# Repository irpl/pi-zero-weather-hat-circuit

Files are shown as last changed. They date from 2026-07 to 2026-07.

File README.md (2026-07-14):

# Raspberry Pi Zero Weather Station HAT — Circuit

Design and manufacturing files for a custom Raspberry Pi Zero HAT that drives a weather station kit. Fabricated November 2020.

The board reads temperature and humidity from a **BME280**, and interfaces the kit's outdoor sensors — a wind vane, an anemometer, and a tipping-bucket rain gauge — through two RJ11/RJ12 jacks. Because the Pi has no analogue inputs, an **MCP3008** ADC on the Pi's SPI bus reads the wind vane's resistive output.

The board outline, mounting holes, and GPIO header come from [mikelawrence/RPi_Zero_pHat_Template](https://github.com/mikelawrence/RPi_Zero_pHat_Template); everything else is my own design.

**Firmware:** [pi-weather](https://github.com/irpl/pi-weather) — the Python that runs on the Pi.

| Gerber render — top | Gerber render — bottom |
|---|---|
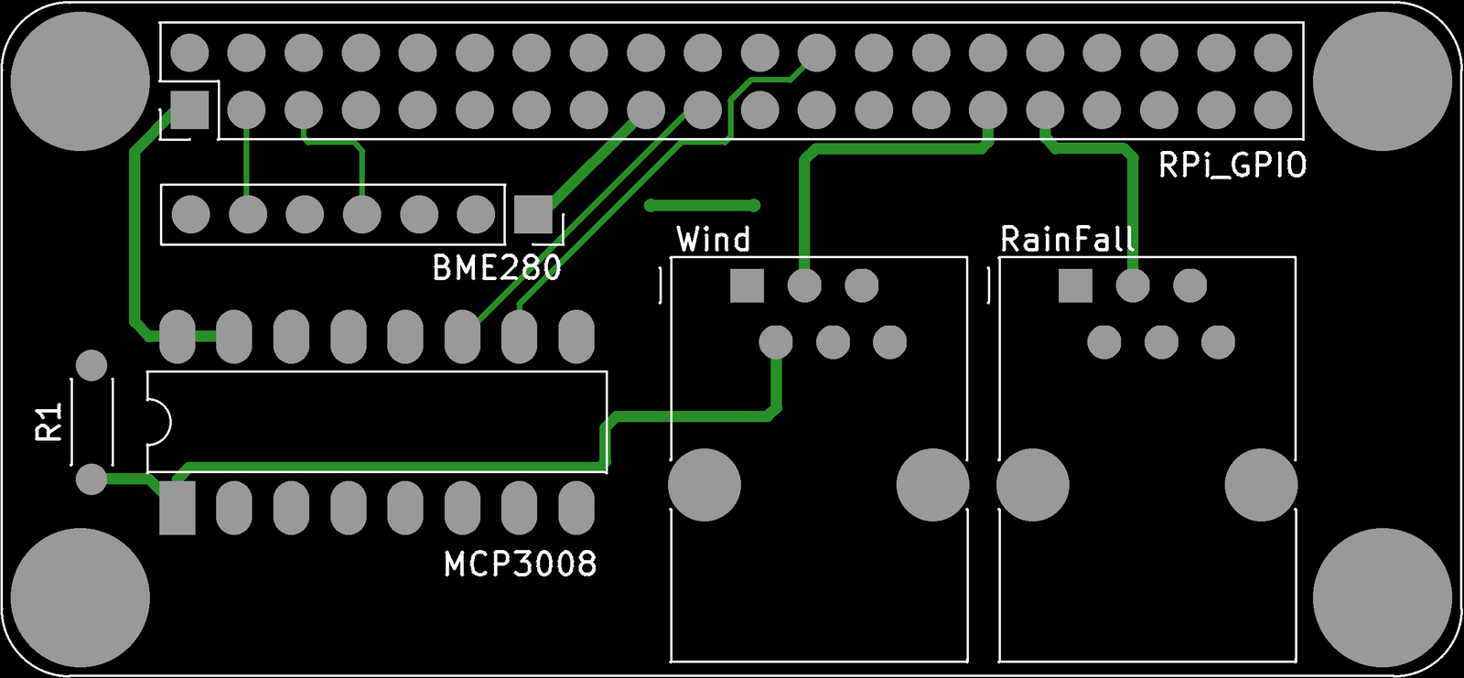
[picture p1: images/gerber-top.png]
Top
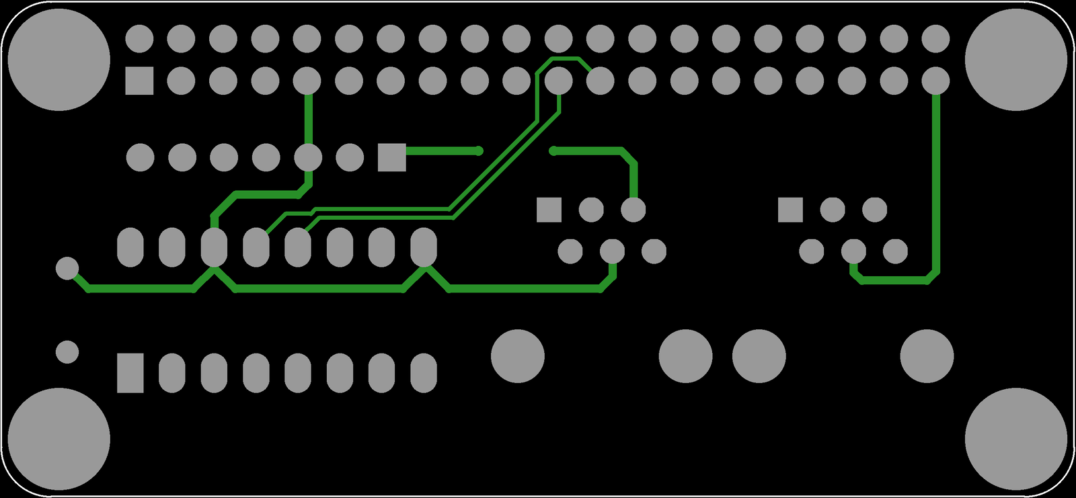
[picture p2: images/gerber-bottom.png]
Bottom
|  |  |

## Manufacturing files

[`gerbers/`](gerbers/) holds the exact set sent to the fab: Gerbers for both copper layers, soldermask, silkscreen, board outline, plus the Excellon drill file. The board is reproducible from these as-is.

- Two-layer, 65 × 30 mm (Raspberry Pi HAT form factor)
- 87 drilled holes; 7 drill sizes from 0.40 mm to 3.25 mm
- Generated by KiCad 5.1.6

## Reconstructed schematic and layout

**The original KiCad project files were lost.** Only the Gerbers survived, so the schematic and board in [`reconstructed/`](reconstructed/) were rebuilt from them — see [`reconstructed/`](reconstructed/) for the scripts that did it.

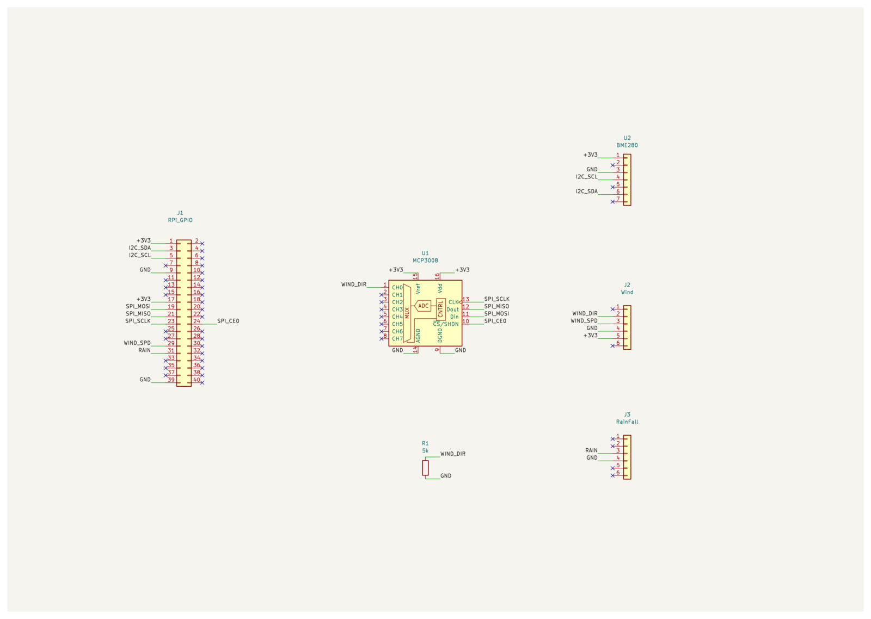
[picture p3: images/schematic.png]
Schematic


*Full resolution: [`reconstructed/schematic.pdf`](reconstructed/schematic.pdf). The recovered layout, plotted from the reconstructed `.kicad_pcb`:*

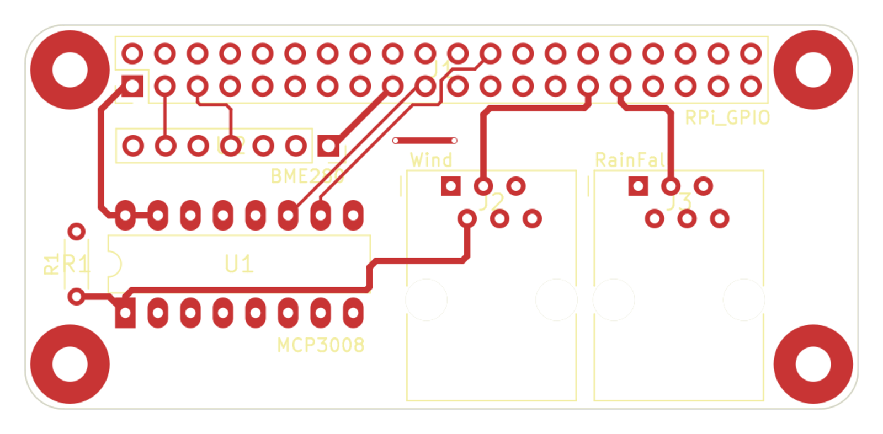
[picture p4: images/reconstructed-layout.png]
Reconstructed layout


The netlist is not a guess. Gerbers contain no connectivity, but the copper does: running a union-find over the pads and track segments (a plated hole ties the two layers together) recovers the netlist that was actually manufactured. That result is independently corroborated by the firmware — `wind_spd.py` uses `Button(5)` and the copper routes the Wind jack to GPIO5; `rain_fall.py` uses `Button(6)` and the copper routes RainFall to GPIO6; `wind_dir.py` reads `MCP3008(channel=0)` and the copper routes the vane to CH0.

### Circuit

- **MCP3008** on the Pi's hardware SPI — `SCLK`/`MISO`/`MOSI`/`CE0` on GPIO 11/9/10/8. `VDD` and `VREF` on 3V3.
- **Wind vane** — 3V3 feeds the vane through the Wind jack; the wiper returns to `CH0`, with **R1 (5 kΩ)** to ground forming the divider the ADC reads.
- **Anemometer** — reed switch to **GPIO5**.
- **Rain gauge** — reed switch to **GPIO6**.
- **BME280** — I²C on `GPIO2 (SDA)` / `GPIO3 (SCL)`, address `0x77`.

### Jack pinout

Both jacks use the standard staggered modular footprint: pin numbers advance across the connector, with odd pins in one row and even pins in the other.

| Jack | Pin 2 | Pin 3 | Pin 4 | Pin 5 |
|---|---|---|---|---|
| **Wind** (6P4C) | vane wiper → `CH0` | anemometer → GPIO5 | GND | +3V3 |
| **RainFall** (6P2C) | — | rain gauge → GPIO6 | GND | — |

The reed switches in the anemometer and rain gauge simply short their signal pin to GND; `gpiozero`'s `Button()` enables the Pi's internal pull-ups, so no pull-up resistors are fitted on the board.

**R1 = 5 kΩ.** Component values are not in Gerber data, but this one is pinned down two ways: the colour bands on the fitted resistor read green-black-red, and the empirical voltage table in [`wind_dir.py`](https://github.com/irpl/pi-weather/blob/main/src/wind_dir.py) matches a 5 kΩ divider against the standard vane resistances at every point — a 1 kΩ vane arm gives 3.3 × 5/6 = 2.75 V, and 2.75 is exactly what the table records for 90°.

### Fidelity of the reconstructed board

The `.kicad_pcb` is not a bare tracing: pads are grouped into components with reference designators and pin numbers, and the recovered netlist is applied to pads, tracks and vias. It opens with a working ratsnest and passes connectivity DRC. Contents: 6 components (77 pads), 8 unplated mounting holes, 2 vias, 100 tracks, 11 nets — 87 drilled holes in total, matching the drill file exactly.

Copper geometry was checked against the source Gerbers by re-plotting from the reconstruction and comparing: **0.000 mm difference in total track length on both layers**, pad positions within 1.6 µm (coordinate rounding in the 2020 files), and identical apertures and drill tools.

Two deliberate departures from the artwork, both improvements rather than losses:

- **The board outline is not drawn onto the copper layers.** KiCad 5 plotted Edge.Cuts onto F.Cu and B.Cu as well; that stroke is a plot artifact, not copper, so it is kept on Edge.Cuts only. Copying it into copper would put a trace exactly on the cut line.
- **Mounting-hole mask openings are taken from the mask Gerbers**, preserving the 6.2 mm soldermask keep-out rings around the RJ-jack mounting holes.

DRC reports 4 copper-to-edge-clearance and 1 soldermask-bridge violation. All five are faithful to the original artwork, not artefacts of the conversion: the 2020 design runs copper right up to the board edge and uses generous mask expansion on the 0.1″ headers. Two "unconnected" items are also expected — the +3V3 and GND rails each exist as two separate copper islands on the HAT (Pi pins 1/17 and 9/39) and are only bonded once the board is seated on the Pi.

One quirk faithfully preserved: a 0.66 mm dangling stub on GPIO25 (J1 pin 22), left over in the original copper and connected to nothing.

### What could not be recovered

Gerbers carry geometry, not design intent. These are stated rather than invented:

- **Component values**, other than R1 (5 kΩ, established above). Gerber data has no values, so no BOM can be generated from these files.
- **Library footprints.** Pads carry recovered geometry — correct size, shape, position and drill — but they are not linked to library footprints, so there is no 3D model or pick-and-place data.
- **Silkscreen text** is line art in the Gerbers, so in the reconstructed board it is strokes rather than editable text.

It is a re-spinnable, netlisted board — but it is a reconstruction, not the original project.

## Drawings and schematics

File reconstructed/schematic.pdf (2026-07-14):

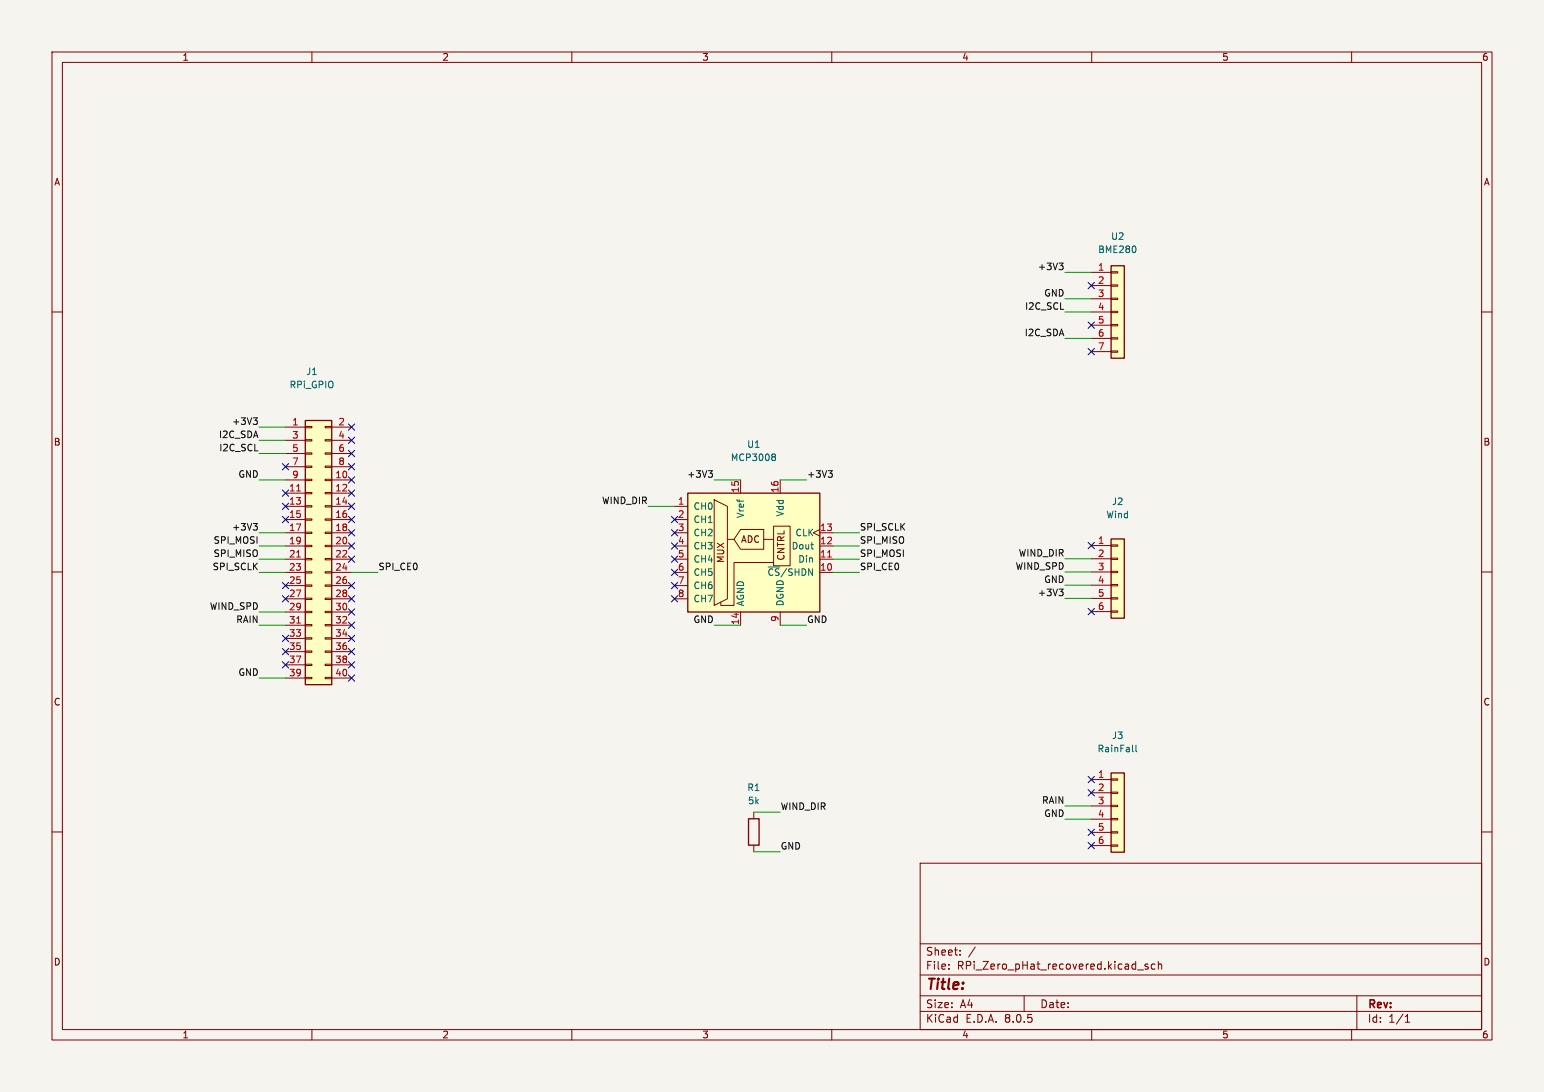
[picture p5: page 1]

Id: 1/1 Title: File: RPi_Zero_pHat_recovered.kicad_sch Sheet: /

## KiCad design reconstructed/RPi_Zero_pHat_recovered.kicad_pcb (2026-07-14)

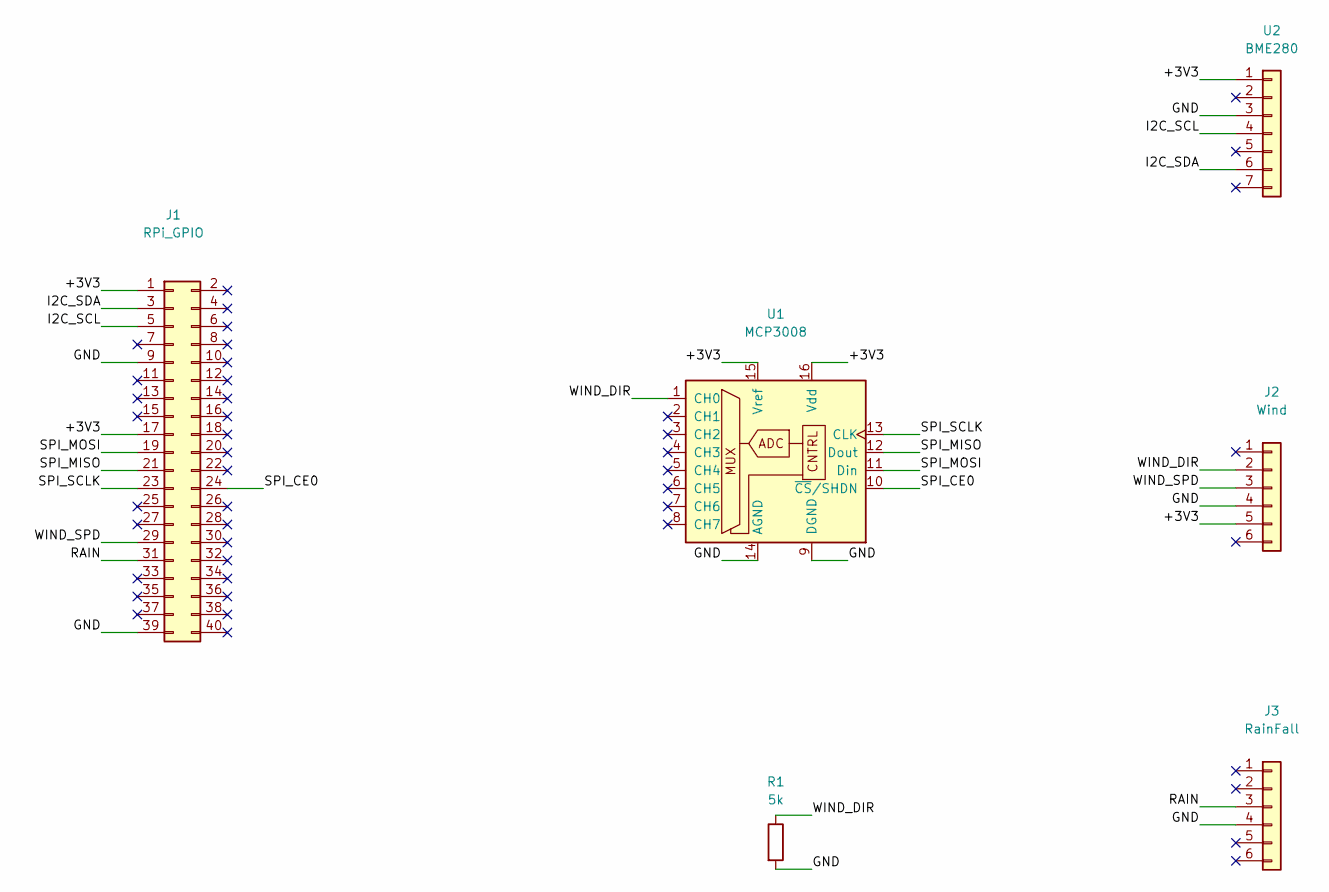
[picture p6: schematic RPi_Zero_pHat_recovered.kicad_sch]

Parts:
J1: RPi_GPIO
J2: Wind
J3: RainFall
R1: 5k
U1: MCP3008
U2: BME280

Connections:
+3V3: J1.1, J1.17, J2.5, U1.15 (Vref), U1.16 (Vdd), U2.1
GND: J1.9, J1.39, J2.4, J3.4, R1.2, U1.9 (DGND), U1.14 (AGND), U2.3
I2C_SCL: J1.5, U2.4
I2C_SDA: J1.3, U2.6
RAIN: J1.31, J3.3
SPI_CE0: J1.24, U1.10 (~CS/SHDN)
SPI_MISO: J1.21, U1.12 (Dout)
SPI_MOSI: J1.19, U1.11 (Din)
SPI_SCLK: J1.23, U1.13 (CLK)
WIND_DIR: J2.2, R1.1, U1.1 (CH0)
WIND_SPD: J1.29, J2.3

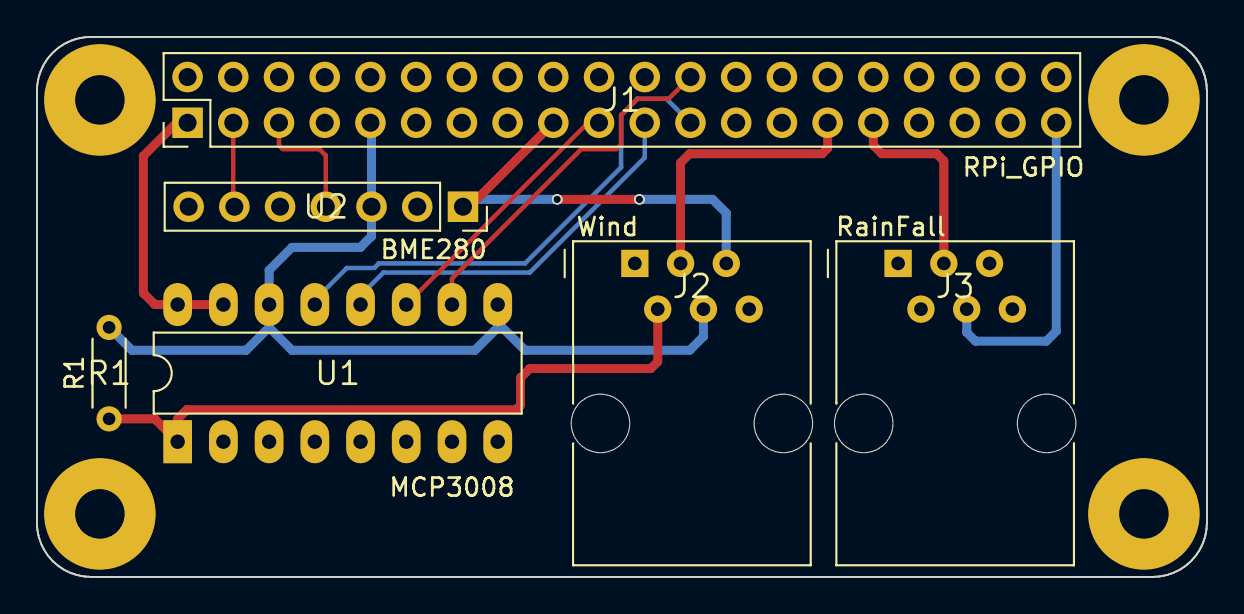
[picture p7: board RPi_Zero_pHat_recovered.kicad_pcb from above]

Board: 2 copper layers, 65.0 x 30.0 mm, 14 parts (0 on the bottom side), 11 nets.

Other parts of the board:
H1, H2, H3, H4, H5, H6, H7, H8: (no value)

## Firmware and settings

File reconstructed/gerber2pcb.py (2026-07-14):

"""Rebuild a netlisted .kicad_pcb from the 2020 JLCPCB Gerber + Excellon set.

Gerbers store artwork, not a design. This script recovers both:

  * geometry  - tracks, pads, vias, board outline and silkscreen, straight from the
                Gerber apertures and the Excellon drill table;
  * electrics - pads are grouped into components (from their pitch and rect pin-1
                markers), and the netlist is recovered by union-find over the copper
                (a plated hole ties F.Cu to B.Cu), then applied to pads, tracks and vias.

The result opens in KiCad with a ratsnest and passes connectivity DRC, unlike a
plain artwork tracing. What is NOT recoverable from Gerbers: component values
(R1 = 5k is known independently) and real footprints - pads carry recovered
geometry, not library footprints.

Run with KiCad's bundled Python, which provides `pcbnew`:
    "C:/Program Files/KiCad/8.0/bin/python.exe" gerber2pcb.py
"""
import re, math, collections
from pathlib import Path
import pcbnew

HERE = Path(__file__).resolve().parent
SRC  = HERE.parent / "gerbers"
OUT  = HERE / "RPi_Zero_pHat_recovered.kicad_pcb"
BASE = "RPi_Zero_pHat_Template"

def nm(mm):  return int(round(mm * 1e6))
def V(x, y): return pcbnew.VECTOR2I(nm(x), nm(-y))   # Gerber Y is up, KiCad Y is down

OUTLINE_W = 0.1    # KiCad 5 plots Edge.Cuts onto the copper layers too; that stroke
                   # is a plot artifact, not copper, and is excluded from the tracks.
VIA_DRILL = 0.45   # 0.40 mm hole + small round pad on both layers = via, not a part

# ---------------------------------------------------------------- gerber / drill
class Gerber:
    """Minimal RS-274X reader: apertures, D01 draws, D02 moves, D03 flashes, G02/G03 arcs."""
    def __init__(self, path):
        self.apertures, self.draws, self.arcs, self.flashes = {}, [], [], []
        self._parse(open(path, errors="ignore").read())

    def _parse(self, text):
        dec = int(re.search(r"%FSLAX(\d)(\d)Y\d\d\*%", text).group(2))
        for am in re.finditer(r"%ADD(\d+)([CROP]),([^*]+)\*%", text):
            self.apertures[int(am.group(1))] = (am.group(2),
                                                [float(v) for v in am.group(3).split("X")])
        scale = 10 ** dec
        x = y = 0.0
        ap = None
        interp = "G01"
        for line in text.splitlines():
            line = line.strip()
            if line.startswith("%") or line.startswith("G04"):
                continue
            dm = re.fullmatch(r"D(\d+)\*", line)
            if dm and int(dm.group(1)) >= 10:
                ap = int(dm.group(1)); continue
            for g in ("G01", "G02", "G03"):
                if line.startswith(g): interp = g
            cm = re.search(r"(?:X(-?\d+))?(?:Y(-?\d+))?(?:I(-?\d+))?(?:J(-?\d+))?D0?([123])\*", line)
            if not cm:
                continue
            nx = int(cm.group(1)) / scale if cm.group(1) else x
            ny = int(cm.group(2)) / scale if cm.group(2) else y
            i  = int(cm.group(3)) / scale if cm.group(3) else 0.0
            j  = int(cm.group(4)) / scale if cm.group(4) else 0.0
            op = cm.group(5)
            if op == "1":
                if interp == "G01": self.draws.append((x, y, nx, ny, ap))
                else:               self.arcs.append((x, y, nx, ny, x + i, y + j, interp == "G03", ap))
            elif op == "3":
                self.flashes.append((nx, ny, ap))
            x, y = nx, ny

def read_drill(path):
    tools, holes, unit_in, cur = {}, [], False, None
    for line in open(path, errors="ignore"):
        line = line.strip()
        if line == "INCH":   unit_in = True
        if line == "METRIC": unit_in = False
        tm = re.fullmatch(r"T(\d+)C([\d.]+)", line)
        if tm:
            d = float(tm.group(2))
            tools[int(tm.group(1))] = d * 25.4 if unit_in else d
            continue
        sm = re.fullmatch(r"T(\d+)", line)
        if sm:
            cur = int(sm.group(1)); continue
        cm = re.fullmatch(r"X(-?[\d.]+)Y(-?[\d.]+)", line)
        if cm and cur in tools:
            x, y = float(cm.group(1)), float(cm.group(2))
            if unit_in: x, y = x * 25.4, y * 25.4
            holes.append((x, y, tools[cur]))
    return holes

layers = {L: Gerber(SRC / f"{BASE}-{L}.gbr")
          for L in ("F_Cu", "B_Cu", "F_Mask", "B_Mask", "F_SilkS", "B_SilkS", "Edge_Cuts")}
holes = read_drill(SRC / f"{BASE}.drl")

# ---------------------------------------------------------------- pads & pin naming
# A plated hole spans both layers, so pads are keyed by position.
pads = {}
for L in ("F_Cu", "B_Cu"):
    g = layers[L]
    for (x, y, ap) in g.flashes:
        shape, dims = g.apertures[ap]
        k = (round(x, 2), round(y, 2))
        e = pads.setdefault(k, {"pos": (x, y), "shape": shape, "dims": dims})
        if shape == "R":                      # rectangular pad = pin 1
            e["shape"], e["dims"] = shape, dims

P = 2.54
def near(a, b, t=0.15): return abs(a - b) < t

RPI = {1:"3V3",2:"5V",3:"GPIO2_SDA",4:"5V",5:"GPIO3_SCL",6:"GND",7:"GPIO4",8:"GPIO14_TXD",
 9:"GND",10:"GPIO15_RXD",11:"GPIO17",12:"GPIO18",13:"GPIO27",14:"GND",15:"GPIO22",16:"GPIO23",
 17:"3V3",18:"GPIO24",19:"GPIO10_MOSI",20:"GND",21:"GPIO9_MISO",22:"GPIO25",23:"GPIO11_SCLK",
 24:"GPIO8_CE0",25:"GND",26:"GPIO7_CE1",27:"ID_SD",28:"ID_SC",29:"GPIO5",30:"GND",31:"GPIO6",
 32:"GPIO12",33:"GPIO13",34:"GND",35:"GPIO19",36:"GPIO16",37:"GPIO26",38:"GPIO20",39:"GND",40:"GPIO21"}

def classify(k):
    """pad key -> (refdes, pin number) using pitch and the rect pin-1 markers."""
    x, y = k
    if near(y, -29.27): return "J1", 2 * round((x - 20.87) / P) + 1
    if near(y, -26.73): return "J1", 2 * round((x - 20.87) / P) + 2
    if near(y, -46.99): return "U1", round((x - 20.32) / P) + 1          # MCP3008 pins 1-8
    if near(y, -39.37): return "U1", 9 + round((38.10 - x) / P)          # MCP3008 pins 9-16
    if near(y, -33.93): return "U2", round((36.17 - x) / P) + 1          # BME280, pin 1 at right
    # RJ11/RJ12 jacks: pads are staggered, not row-major. Pin number advances with x
    # (1.27 mm) while alternating rows - odd pins in pin-1's row, even pins in the other.
    # Contacts inside a modular jack sit side by side; their tails cannot cross.
    for ref, x0 in (("J2", 45.72), ("J3", 60.35)):
        if x0 - 0.2 <= x <= x0 + 6.6 and (near(y, -37.08) or near(y, -39.62)):
            return ref, round((x - x0) / 1.27) + 1
    if near(x, 16.51): return "R1", 1 if near(y, -45.72) else 2
    return None, None

# ---------------------------------------------------------------- recover the netlist
# union-find over pads and copper segments; a plated hole bridges the layers
parent = {}
def find(a):
    parent.setdefault(a, a)
    while parent[a] != a:
        parent[a] = parent[parent[a]]; a = parent[a]
    return a
def union(a, b):
    ra, rb = find(a), find(b)
    if ra != rb: parent[ra] = rb
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

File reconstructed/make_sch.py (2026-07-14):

"""Generate a KiCad schematic whose connectivity is exactly the netlist extracted
from the fabricated board's copper (see extract_nets.py / netlist.py).

Nets are attached with local labels at each pin. Pins the board leaves unconnected
get a no-connect flag, so the schematic states plainly what is and isn't wired.
"""
import re, uuid, os

from pathlib import Path

# Run with plain CPython:  python make_sch.py
# Override the symbol library location with KICAD_SYMBOL_DIR if KiCad lives elsewhere.
HERE = Path(__file__).resolve().parent
LIB  = os.environ.get("KICAD_SYMBOL_DIR", r"C:\Program Files\KiCad\8.0\share\kicad\symbols")
OUT  = HERE / "RPi_Zero_pHat_recovered.kicad_sch"

def U(): return str(uuid.uuid4())

# ---------------------------------------------------------------- symbol loading
def load_symbol(libname, symname):
    """Pull one top-level (symbol "NAME" ...) block out of a .kicad_sym file.

    Symbols may be defined as (extends "PARENT"), which inherits the parent's pins
    and graphics; in that case return the parent's body under the child's name.
    """
    txt = open(os.path.join(LIB, libname + ".kicad_sym"), encoding="utf-8").read()
    start = txt.index(f'(symbol "{symname}"')
    depth, i = 0, start
    while True:
        if txt[i] == "(": depth += 1
        elif txt[i] == ")":
            depth -= 1
            if depth == 0: break
        i += 1
    block = txt[start:i + 1]
    ext = re.search(r'\(extends\s+"([^"]+)"\)', block)
    if ext:
        parent = load_symbol(libname, ext.group(1))
        # keep the parent's body (pins/graphics), present it under the child's name
        pname = ext.group(1)
        block = parent.replace(f'(symbol "{pname}"', f'(symbol "{symname}"', 1)
        block = block.replace(f'(symbol "{pname}_', f'(symbol "{symname}_')   # unit sub-symbols
    return block

def symbol_pins(block):
    """[(number, name, x, y)] - pin connection points in symbol coords."""
    pins = []
    for m in re.finditer(
        r"\(pin\s+\w+\s+\w+\s*\(at\s+(-?[\d.]+)\s+(-?[\d.]+)\s+(-?[\d.]+)\)"
        r".*?\(name\s+\"([^\"]*)\".*?\(number\s+\"([^\"]*)\"",
        block, re.S):
        x, y, ang, nm, num = m.groups()
        pins.append((num, nm, float(x), float(y), float(ang)))
    return pins

PARTS = {                       # ref -> (lib, symbol, value, x, y, ref_dy)
    "J1": ("Connector_Generic", "Conn_02x20_Odd_Even", "RPi_GPIO",  60,  105, 31.0),
    "U1": ("Analog_ADC",        "MCP3008",             "MCP3008",  145,  105, 17.0),
    "U2": ("Connector_Generic", "Conn_01x07",          "BME280",   215,   60, 12.0),
    "J2": ("Connector_Generic", "Conn_01x06",          "Wind",     215,  110, 11.0),
    "J3": ("Connector_Generic", "Conn_01x06",          "RainFall", 215,  155, 11.0),
    "R1": ("Device",            "R",                   "5k",       145,  160,  6.0),
}

# net -> [(ref, pin), ...]   (taken verbatim from the copper extraction)
# RJ jack pads are staggered: pin number advances with x while alternating rows,
# so Wind lands on pins 2-5 (a 6P4C plug) and RainFall on the centre pair 3-4 (6P2C).
NETS = {
    "GND":      [("J1","9"),("J1","39"),("J2","4"),("J3","4"),("R1","2"),
                 ("U1","9"),("U1","14"),("U2","3")],
    "+3V3":     [("J1","1"),("J1","17"),("J2","5"),
                 ("U1","15"),("U1","16"),("U2","1")],
    "SPI_SCLK": [("J1","23"),("U1","13")],
    "SPI_MISO": [("J1","21"),("U1","12")],
    "SPI_MOSI": [("J1","19"),("U1","11")],
    "SPI_CE0":  [("J1","24"),("U1","10")],
    "I2C_SDA":  [("J1","3"),("U2","6")],
    "I2C_SCL":  [("J1","5"),("U2","4")],
    "WIND_SPD": [("J1","29"),("J2","3")],
    "RAIN":     [("J1","31"),("J3","3")],
    "WIND_DIR": [("J2","2"),("R1","1"),("U1","1")],
}

# ---------------------------------------------------------------- build
lib_blocks, pin_map = {}, {}
for ref, (lib, sym, val, sx, sy, rdy) in PARTS.items():
    blk = load_symbol(lib, sym)
    lib_id = f"{lib}:{sym}"
    if lib_id not in lib_blocks:
        # rename the block to the fully-qualified lib_id for the lib_symbols section
        lib_blocks[lib_id] = blk.replace(f'(symbol "{sym}"', f'(symbol "{lib_id}"', 1)
    pin_map[ref] = {num: (x, y, ang, nm) for num, nm, x, y, ang in symbol_pins(blk)}

connected = {(r, p) for pins in NETS.values() for (r, p) in pins}

SHEET_UUID = U()
out = ['(kicad_sch (version 20231120) (generator "gerber_recovery") (generator_version "8.0")',
       f'  (uuid "{SHEET_UUID}")', '  (paper "A4")', '  (lib_symbols']
for lib_id, blk in lib_blocks.items():
    out.append("    " + blk)
out.append("  )")

def abs_pin(ref, num):
    sx, sy = PARTS[ref][3], PARTS[ref][4]
    px, py, ang, _ = pin_map[ref][num]
    return sx + px, sy - py          # symbol Y is up, sheet Y is down

for ref, (lib, sym, val, sx, sy, rdy) in PARTS.items():
    out.append(f'  (symbol (lib_id "{lib}:{sym}") (at {sx} {sy} 0) (unit 1)')
    out.append('    (exclude_from_sim no) (in_bom yes) (on_board yes) (dnp no)')
    out.append(f'    (uuid "{U()}")')
    out.append(f'    (property "Reference" "{ref}" (at {sx} {sy - rdy - 2.54} 0)'
               f' (effects (font (size 1.27 1.27))))')
    out.append(f'    (property "Value" "{val}" (at {sx} {sy - rdy} 0)'
               f' (effects (font (size 1.27 1.27))))')
    for num in pin_map[ref]:
        out.append(f'    (pin "{num}" (uuid "{U()}"))')
    out.append('    (instances (project "RPi_Zero_pHat_recovered"')
    out.append(f'      (path "/{SHEET_UUID}" (reference "{ref}") (unit 1))))')
    out.append("  )")

# labels + short wire stubs, and no-connects on unwired pins
for net, pins in NETS.items():
    for (ref, num) in pins:
        x, y = abs_pin(ref, num)
        px = pin_map[ref][num][0]
        dx = 5.08 if px >= 0 else -5.08          # stub away from the symbol body
        out.append(f'  (wire (pts (xy {x} {y}) (xy {x + dx} {y}))'
                   f' (stroke (width 0) (type default)) (uuid "{U()}"))')
        just = "left" if dx > 0 else "right"
        out.append(f'  (label "{net}" (at {x + dx} {y} 0) (fields_autoplaced yes)'
                   f' (effects (font (size 1.27 1.27)) (justify {just} bottom)) (uuid "{U()}"))')

for ref in PARTS:
    for num in pin_map[ref]:
        if (ref, num) not in connected:
            x, y = abs_pin(ref, num)
            out.append(f'  (no_connect (at {x} {y}) (uuid "{U()}"))')

out.append(')')
open(OUT, "w", encoding="utf-8").write("\n".join(out))
print("wrote", OUT)
print("parts:", len(PARTS), " nets:", len(NETS),
      " connected pins:", len(connected),
      " no-connects:", sum(1 for r in PARTS for n in pin_map[r] if (r, n) not in connected))

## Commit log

2026-07-14 Raspberry Pi Zero weather station HAT: Gerbers, schematic, layout
    Fab-ready Gerber and drill set from the November 2020 JLCPCB order. The
    original KiCad project was lost, so the schematic and layout here were
    reconstructed from the copper: the netlist was recovered by tracing pads
    and tracks, then cross-checked against the pi-weather firmware.
    Conversion scripts included and runnable from a clone.
    [RPi_Zero_pHat_Template-B_Cu.gbr, RPi_Zero_pHat_Template-B_Mask.gbr, RPi_Zero_pHat_Template-B_SilkS.gbr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]
2026-07-14 Drop KiCad local-state file; add .gitignore
2026-07-14 Recover netlist and refdes onto the board; fix mounting-hole mask openings
    The .kicad_pcb now carries components with reference designators, numbered
    pads, and the recovered netlist on pads/tracks/vias - it opens with a
    ratsnest and passes connectivity DRC. Mounting-hole soldermask openings are
    taken from the mask gerbers (the 6.2mm keep-out rings were previously lost).
    Board outline is no longer duplicated onto the copper layers.
    [RPi_Zero_pHat_recovered.kicad_pcb]
2026-07-14 Fix RJ jack pin numbering: pads are staggered, not row-major
    The modular-jack footprint numbers pins across the connector (1.27mm in x)
    with odd pins in one row and even in the other, not row-major. With the
    correct numbering Wind lands on pins 2-5 (a 6P4C plug) and RainFall on the
    centre pair 3-4 (6P2C) - contiguous, as real modular plugs require. The
    previous numbering put +3V3 on the anemometer common, so a cable built from
    it would have shorted 3V3 to ground.
    Adds a jack pinout table to the README.
    [RPi_Zero_pHat_recovered.kicad_pcb, RPi_Zero_pHat_recovered.kicad_sch]
